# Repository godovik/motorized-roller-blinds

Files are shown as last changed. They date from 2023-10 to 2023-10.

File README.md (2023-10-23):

# motorized-roller-blinds

Проект для автоматизации управления рулонными шторами на платформе ESP8622.
В этом репозитории вы найдете все необходимые файлы для самостоятельной сборки и настройки электропривода для рулонных штор.

## [Wiki](https://github.com/godovik/motorized-roller-blinds/wiki)

## Содержание репозитория

- **motorized-roller-blinds.ino**: файл для самостоятельной сборки прошивки для ESP8622
- **libraries**: папка с дополнительными библиотеками, для самостоятельной сборки прошивки
- **pcb**: папка с файлами для изготовления печатной платы
- **3d-models**: папка с `.stl` файлами для самостоятельной печати корпуса для привода (в процессе наполнения)

Так же `.stl` файлы можно найти на странице проекта на [thingiverse](https://www.thingiverse.com/thing:6279068)

## Запланированные изменения

- добавить поддержку ручного управления шторой
- перевести плату на 12V
- добавить поддержку моторов NEMA 
- поддержка рассписания открытия/закрытия без необходимости подключения к интернету

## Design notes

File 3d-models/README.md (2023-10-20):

## front-motor
Кронштейн с мотором, расположенным сбоку. Вал шторы надеватся непосредственно на вал мотора. Цифра в названии файла указывает на расстояние от окна до центра вала шторы/мотора.

todo: добавить чертеж с указанием измеряемого расстояния

## side-motor
*находится в процессе наполнения*

Кронштейн с мотором, расположенным рядом с валом шторы. Используется, если очень важно сохранить расстояние по ширине. Например, когда несколько штор висят вплотную друг к другу.

## screw-mount
Модификация кронштейна, с креплением на саморезы.

## clip-mount
*находится в процессе наполнения*

Модификация кронштейна, с креплением на откидные окна. Без использования саморезов.

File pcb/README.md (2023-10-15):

## PCB_motorized-roller-blinds.json: 
Актуальная используемая печатная плата. 
В ней не совсем удачно сделаны крепежные отверстия - крепежный винт конфликтует с разъемом питания. Поэтому для монтажа будет необходимо использовать саморез с маленькой шляпкой.

## PCB_motorized-roller-blinds_BETA.json
Версия платы, которая будет использована в будущем. 
В ней исправлена проблема с крепежными отверсиями. Так же добавлены дополнительные пины для подключения внешнего датчика. Например освещенности.

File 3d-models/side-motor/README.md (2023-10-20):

## [roller.stl](https://github.com/godovik/motorized-roller-blinds/3d-models/side-motor/roller.stl) - вал, надеваемый на мотор

## screw-mount
Модификация кронштейна, с креплением на саморезы.

## clip-mount
*находится в процессе наполнения*

Модификация кронштейна, с креплением на откидные окна. Без использования саморезов.

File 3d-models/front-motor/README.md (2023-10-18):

## screw-mount
Модификация кронштейна, с креплением на саморезы.

## clip-mount
Модификация кронштейна, с креплением на откидные окна. Без использования саморезов.

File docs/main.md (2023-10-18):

## Сборка контроллера

### Необходимые компоненты
- контроллер `ESP-12` - 1шт
- датчик холла `A3144` - 2шт
- smd-резистор `0805 10K` - 6шт 
- smd-конденсатор` 0805 1UF` - 1шт 
- линейный стабилизатор `AMS1117` - 1шт
- `ULN2003 SOP-16` - 1шт
- шаговый двигатель 28BYJ-48 - 1шт

### Особенности
Компоненты необходимо распаять на плате согласно схеме `PCB_motorized-roller-blinds`.
Датчик холла `h1` должен быть поднят максимально далеко от поверхности платы.
Датчик холла `h2` должен быть опущен как можно ниже - длина ножек над повернхостью платы не должна превышать 5мм.
Для прошивки, к соответсвующим пинам рекомендую припаять однорядные пины типа "папа" на 90 градусов. 

Распаять необходимо только один разъем питания. С той стороны, с которой вы будете подводить питание к контроллеру.

## Cборка прошивки

1. Для самостоятельной сборки прошивки вам потребуется установить несколько библиотек в Arduino IDE:
- [EEPROM](https://github.com/PaulStoffregen/EEPROM)
- [GyverHub](https://github.com/GyverLibs/GyverHub)
- [GyverStepper](https://github.com/GyverLibs/GyverStepper)

2. Библиотеки из папки `libraries` необходимо скопировать в `~/Arduino/libraries`. 
Можно использовать симлинк: 
```
ln -s motorized-roller-blinds/libraries/ ~/Arduino/libraries/motorized-roller-blinds-libraries
```

3. Открыть `motorized-roller-blinds.ino` в Arduino IDE
4. Выполнить `Скетч -> Экспорт бинарного файла`

## Прошивка контроллера

Для прошивки контроллера потребуется Usb-TTL конвертер.

**Важно!** Пин `rx` на контроллере надо соединять с пином `tx` на конвертере, а пин `tx` с `rx`.

Для перевода контроллера в режим прошивки, надо будет замкнуть пины `flash` и `reset` на `gnd`.
Чтобы упростить эту процедуру, рекомендую разместить кнопки на макетной плате:

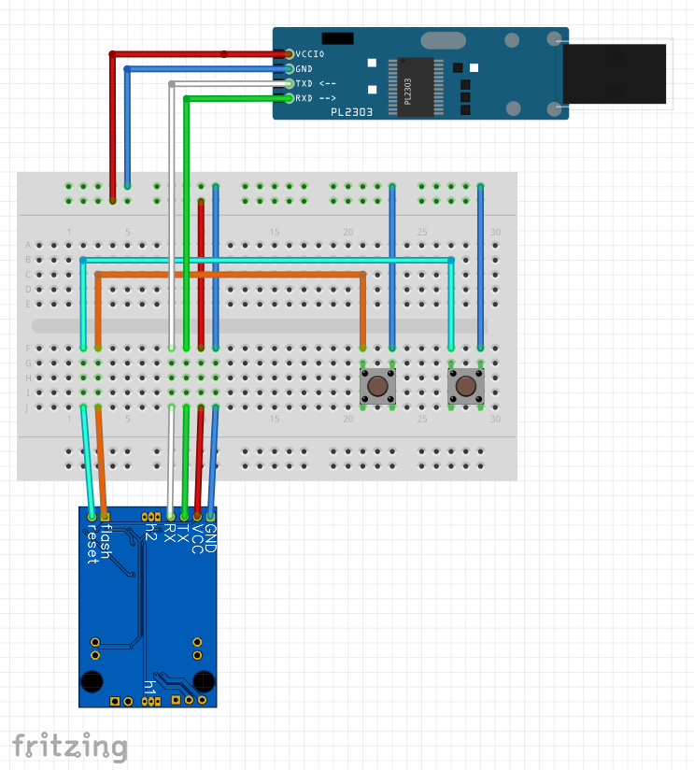
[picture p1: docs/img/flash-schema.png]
alt=flash-schema


## Сборка устройства

_Видео с инструкцией в процессе записи_

## Настройка шторы

### Подключение к WiFi
1. После подключения питания, контроллер попытается подключиться к сети WiFi. Если ему это не удается, он переключается в режим точки доступа. Для подключения к ней откройте настройки WiFi на устройстве, обновите список сетей и подключитесь к сети `Roller Blind`.

2. После успешного подключения перейдите в GyverHub и обновите список устройств. В списке доступных устройств появится новое:

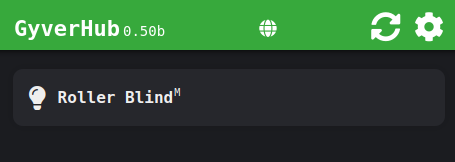
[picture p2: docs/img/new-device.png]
alt=new-device


3. Перейдите на страницу устройства. Откройте меню устройства и выберите `Настройки WiFi`

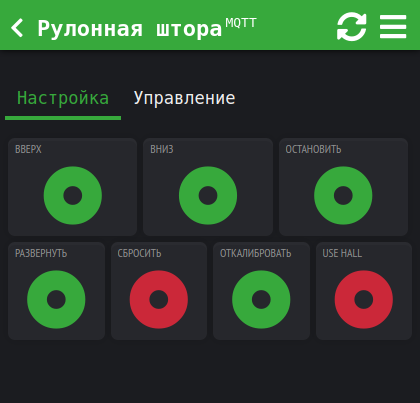
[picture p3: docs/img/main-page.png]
alt=main-page

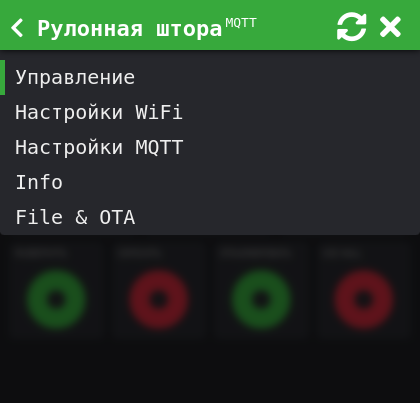
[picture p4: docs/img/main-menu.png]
alt=main-menu


4. Введите данные для подключения к вашему WiFi и нажмите `Подключиться`

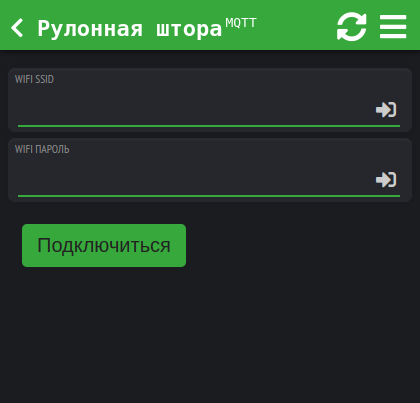
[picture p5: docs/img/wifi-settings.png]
alt=wifi-settings


Контроллер запомнит настройки, перезагрузится и попытается подключиться к WiFi

### Калибровка шторы
1. На вкладке `Настройка` нажмите кнопку `Вверх`.
    1. Если штора движется вниз, нажмите кнопку `Развернуть`.
2. Внизу шторы закрепите магнит. По достижении верхнего положения магнит должен оказаться напротив датчика холла `h2`.
3. Удостоверьтесь, что магнит повернут к датчику правильным полюсом.
    1. При помощи нескольких нажатий на кнопку `Стоп` активируйте режим отладки.
    2. Приложите магнит к датчику холла `h2`.
    3. Индикатор `top hall` должен загореться зеленым.
4. При помощи кнопки `Вниз` опустите штору в нижнее положение.
5. Нажмите кнопку `Откалибровать`.
6. Штора начнет подниматься. По достижении датчика холла длина шторы будет сохранена. Устройство перезагрузится.

## Подключение к умному дому Yandex

### Подключение к mqtt-брокеру на примере [wqtt](https://wqtt.ru)
1. Перейдите на страницу с информацией о настройках брокера: https://dash.wqtt.ru/broker/
2. Откройте меню устройства и выберите `Настройки mqtt`

alt=main-menu

3. Скопируйте адрес, порт, логин и пароль со страницы брокера в настройки шторы
4. Нажмите `Подключиться`

Контроллер запомнит настройки. Если данные верны - соединение будет установлено сразу.

### Добавление нового устройства в умный дом брокера на примере [wqtt](https://wqtt.ru)
1. Откройте меню устройства и выберите пункт `Info`. Запомните `ID` устройства
 
alt=main-menu

2. Перейдите в настройки GyverHub и запомните `Client ID`
3. Откройте страницу настроек брокера: https://dash.wqtt.ru/settings/
4. Добавьте новое устройство:
    1. Нажмите кнопку `Добавить устройство`
    2. Выберите `Шторы`
5. Введите название шторы и укажите, в какой комнате она находится
6. Добавьте обработчик команды открытия шторы:
    1. Нажмите кнопку `Добавить` в органах управления
    2. Выберите пункт `Выключатель питания`
    3. В поле `Топик управления` введите `MyDevices/<device-id>/<client-id>/set/opened`. 
    4. В поле `Топик состояния` введите `MyDevices/<device-id>/<client-id>/read/opened`. 
    5. В поле `Команда включить` введите `1`. 
    6. В поле `Топик выключить` введите `0`. 
    7. Нажмите `Сохранить`. 
7. Добавьте обработчик команды установки положения шторы:
    1. Нажмите кнопку `Добавить` в органах управления
    2. Выберите пункт `Открывание`
    3. В поле `Топик управления` введите `MyDevices/<device-id>/<client-id>/set/percent_position`. 
    4. В поле `Топик состояния` введите `MyDevices/<device-id>/<client-id>/read/percent_position`. 
    5. В поле `Множитель` введите `1`. 
    6. В поле `Мин` введите `0`. 
    7. В поле `Макс` введите `100`. 
    8. В поле `Шаг` введите `1`.  
    9. Нажмите `Сохранить`. 
8. Нажмите `Сохранить`. 
9. Добавьте новое устройство в умный дом яндекса
    1. Если ранее уже настроили интеграцию с wqtt, то на [странице настроек wqtt](https://dash.wqtt.ru/settings/) нажмите `Обновить устройства Яндекс`
    2. Если интеграция не настроена, нажмите `Добавить новое устройство` и в предложенном списке производителей выберите `Устройства WQTT`

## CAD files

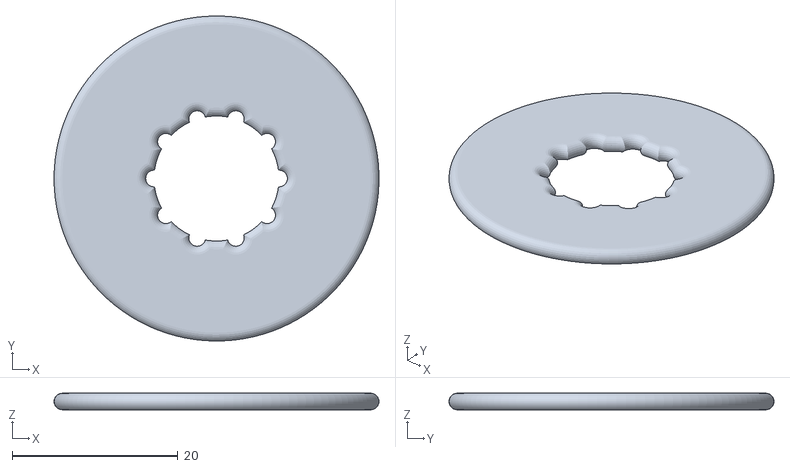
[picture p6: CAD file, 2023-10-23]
3d-models/side-motor/roller-ring-38mm.stl
39.2 x 39.2 x 2.01

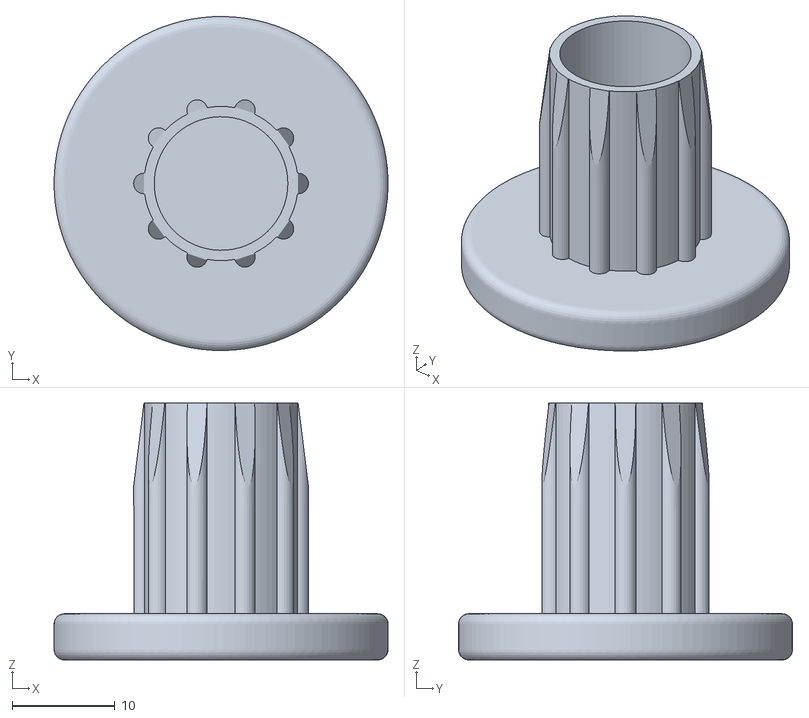
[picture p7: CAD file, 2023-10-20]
3d-models/side-motor/roller.stl
32.5 x 32.5 x 25.0

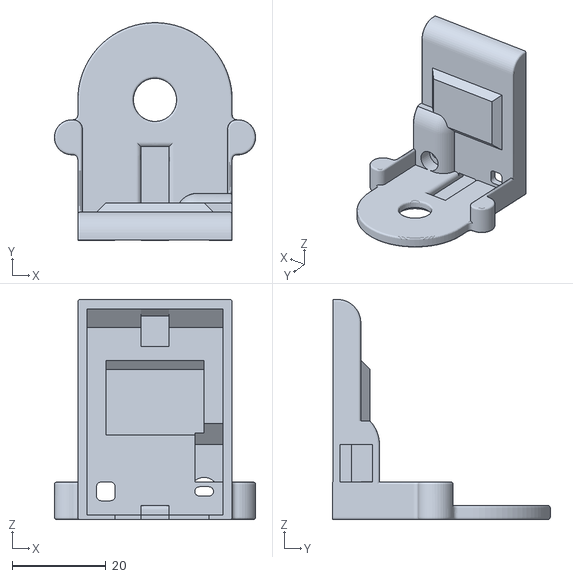
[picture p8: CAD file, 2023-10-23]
3d-models/side-motor/screw-mount/30mm/body-30mm-screw.stl
43.0 x 46.5 x 47.0

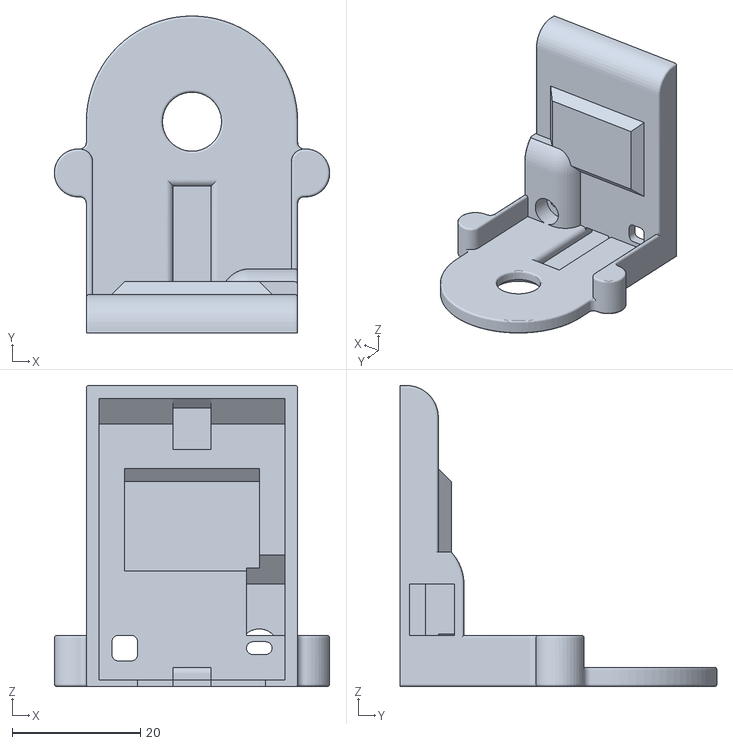
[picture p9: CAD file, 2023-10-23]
3d-models/side-motor/screw-mount/33mm/body-33mm-screw.stl
43.0 x 49.5 x 47.0

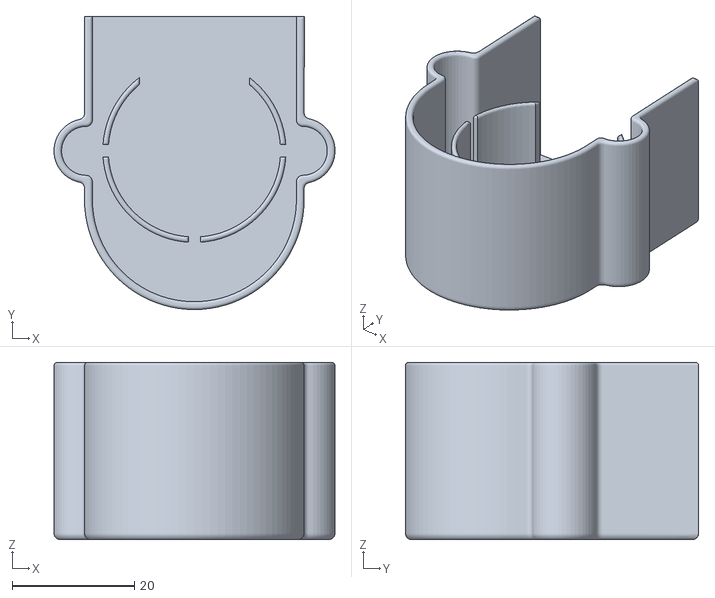
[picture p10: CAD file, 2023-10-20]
3d-models/side-motor/screw-mount/30mm/motor-box-30mm-screw.stl
46.0 x 48.0 x 29.0

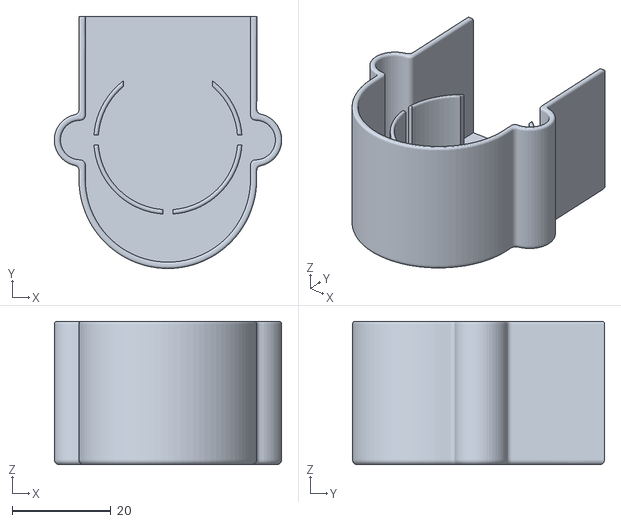
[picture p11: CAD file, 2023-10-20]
3d-models/side-motor/screw-mount/33mm/motor-box-33mm-screw.stl
46.0 x 51.0 x 29.0

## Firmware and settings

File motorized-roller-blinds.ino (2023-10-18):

#define ATOMIC_FS_UPDATE // OTA обновление сжатым .gz файлом (вместо .bin)
#define ROLLER_BLIND_LANG_RU

#include <Arduino.h>
#include <EEPROM.h>
#include <GyverStepper.h>
#include <GyverHub.h>
#include <RollerBlindConsts.h>
#include <EepromSync.h>
#include <HubWiFiSettings.h>
#include <HubMqttSettings.h>
#include <HubMotorSettings.h>
#include <RollerBlindInterface.h>

// todo: allow ability to rename 
GyverHub hub(DEVICES_GROUP, NAME, ICON);
GStepper <STEPPER4WIRE, STEPPER_VIRTUAL> motor(2048);

HubWiFiSettings       wifiSettings(&hub);
HubMqttSettings       mqttSettings(&hub);
HubMotorSettings      motorSettings(&hub);
RollerBlind           rollerBlind(&motor, &motorSettings);
RollerBlindInterface  rollerBlindInterface(&hub, &rollerBlind);


void readSettings() {
  wifiSettings.read();
  mqttSettings.read();
  motorSettings.read();
}

void build() {
  if (hub.Menu(F(MAIN_MENU))) {
    hub.refresh();
  }

  switch (hub.menu) {
    case 0:
      rollerBlindInterface.draw();
      break;

    case 1:
      wifiSettings.draw();
      break;
      
    case 2:
      mqttSettings.draw();
      break;
      
    case 3:
      motorSettings.draw();
      break;
  }
}

void onReboot(GHreason_t reason) {
  hub.turnOff();
}

void setupHub() {
  hub.onBuild(build);
  hub.onReboot(onReboot);
  hub.begin();
  hub.turnOn();
}

void setup() {
  Serial.begin(115200);
  EEPROM.begin(EEPROM_SIZE);

  Serial.println("============================================================");
  Serial.println("============================================================");
  Serial.println("============================================================");
  Serial.println("============================================================");
  Serial.println("============================================================");
  Serial.println("============================================================");

  readSettings();
  wifiSettings.connect();
  mqttSettings.connect();
  setupHub();
  rollerBlind.setup();
  rollerBlindInterface.setup();
}

void loop() {
  hub.tick();
  rollerBlind.tick();
  rollerBlindInterface.updateValues();
}

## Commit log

2023-10-15 add pcb files
    [PCB_motorized-roller-blinds.json, PCB_motorized-roller-blinds_BETA.json, motorized-roller-blinds.json]
2023-10-15 add setup instruction
    [PCB_motorized-roller-blinds.json, PCB_motorized-roller-blinds_BETA.json]
2023-10-18 add motor pins setup page
2023-10-18 fix virtual driver usage
2023-10-20 add .stl files
    [body-30mm-screw.stl, body-33mm-screw.stl, motor-box-30mm-screw.stl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]
2023-10-23 Fix body models
    [body-30mm-screw.stl, body-33mm-screw.stl]
2023-10-23 Scale roller ring
    [roller-ring-38mm.stl]
2023-10-27 fix button text
2023-11-10 update new version of the pcb
    [PCB_motorized-roller-blinds_BETA.json, motorized-roller-blinds.json]
